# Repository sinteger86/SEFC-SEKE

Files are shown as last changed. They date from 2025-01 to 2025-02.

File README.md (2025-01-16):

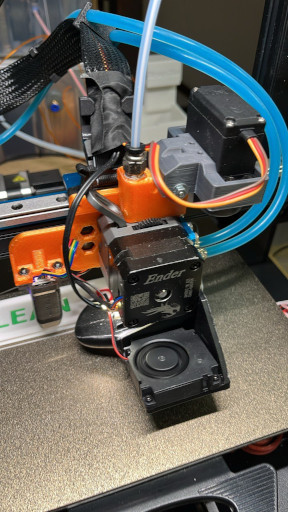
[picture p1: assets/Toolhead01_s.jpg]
Toolhead with SEFC

# SEFC
Sprite Extruder Filament Cutter

After building the ERCF, v1.1 in my case, I went through the battle of calibrate it.
Everything went fine, after I found the right top hats. But, the tip forming calibration
time arrived! And I didnt, and still dont, use a Voron-style toolhead, so there is no 
filament sensors. I spent many hours, asked in the forums and channels, but I wasnt able
to have it in a reliable way. It worked but not always :(

So I decided to look for a filament cutter. I bought a EREC kit from AliExpress and I was
thinking to upgrade my ERCF from version 1.1 to version 2.0. But I started to pay attencion
in the tip that I was getting from the tip forming process. It was not regular when it didnt
work, sometimes a very long string sometimes a short one, and I thought how will EREC deal with
these situations?

Then I decide to look for a toolhead filament cutter, but most of the projects were for a Voron-like
toolhead, until I found the "Sprite Extruder Filament Cutter (SEFC)" from DrawModelPrint, 
https://www.thingiverse.com/thing:6629071.

I built it but didn't work for me as the stepmotor couldnt press the arm strong enough to cut 
the filament.

I decided to look for a filament cutter servo-driven, but I couldnt find any project for the
sprite extruder. At some point I came across with the "Filament-Cutter for Bondtech LGX-Lite Extruder"
from technik.gegg, https://thangs.com/designer/technik.gegg/3d-model/Filament-Cutter%20for%20Bondtech%20LGX-Lite%20Extruder-69552.

I tought then, how about I merge these two projects With that, SEFC was born.

Today I am using it and it has been working fine so far. It is not perfect but it does the job. 

As the printer is using the original board, there is no available pin to connect the servo control,
to overcome it, I bought a RP2040 Zero from AliExpress and connect it to the PAD7 (or SonicPad) and 
add the configuration and macros. 

If you build it, let me know how it works for you. 

## Material

1x Compression Spring 15mm 0.4mm OD (0.4x5x15mm) 
    https://amzn.eu/d/ak1jHkr
1x Blade #4 (need to cut it so the body is 10mm outside the block) 
    https://www.amazon.nl/dp/B08J6G87PL
    I bought this kit as I was trying different blade models
1x Servo MG996R from the EREC kit from Seleadlab (AliExpress)
    https://a.aliexpress.com/_EIvgRve
    I only used the servo
1x Straight Pneumatic Push fittings
    https://www.amazon.nl/dp/B0D87GVJ92

and the parts to print in the STL folder

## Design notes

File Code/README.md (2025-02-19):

# Configuration Section
The configuration is based on adding 2 files (in my case, as I used a RP2040Zero to drive the servo):

## Servo Board (RP2040Zero)
Filename: rp2040.cfg
Include position at printer.cfg: Any place.
Description: This file create the servo and led pins that are used by the macros

## Cutter macro
Filename: tip-cutter.cfg
Include position at printer.cfg: Before the mmu configuration
Description: This file contains the macros that will perform the filament purge and cut. 

## Example:
[include tip-cutter.cfg]
[include mmu/base/*.cfg]
[include mmu/optional/client_macros.cfg]
[include rp2040.cfg]
[include mainsail.cfg]

# Happy-Hare configuration:
on "mmu_macro_vars.cfg":
    variable_user_post_load_extension     : 'MCPURGE'	; Executed after default logic but before restoring toolhead position

on "mmu_parameters.cfg":
    post_form_tip_macro: MCCUTTIP			# Called immediately after tip forming

"Fake" tip forming:
variable_cooling_tube_position  : 30		; Start of cooling tube. DragonST:35, DragonHF:30, Mosquito:30, Revo:35, RapidoHF:27
variable_cooling_tube_length    : 1		; Movement length. DragonST:15, DragonHF:10, Mosquito:20, Revo:10, RapidoHF:10
variable_initial_cooling_speed  : 2.2		; Inital slow movement (mm/s) to solidify tip and cool string if formed
variable_final_cooling_speed    : 30		; Fast movement (mm/s) Too fast: tip deformation on eject, Too Slow: long string/no seperation
variable_cooling_moves          : 1		; Number of back and forth cooling moves to make (2-4 is a good start)

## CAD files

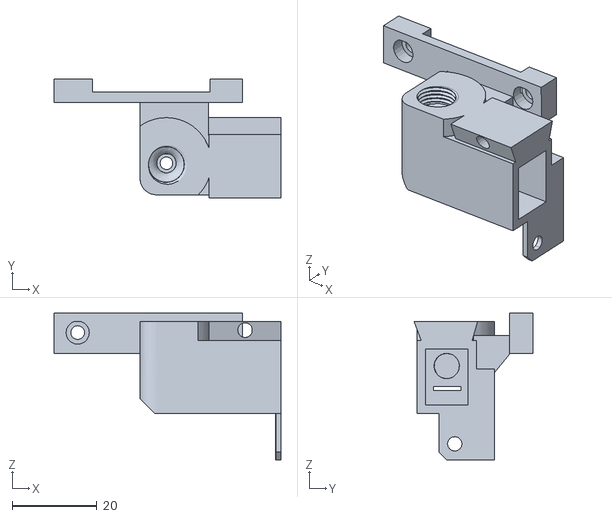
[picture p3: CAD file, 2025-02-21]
STL/SEFC-SEKE v0.91.stl
53.7 x 28.1 x 34.7

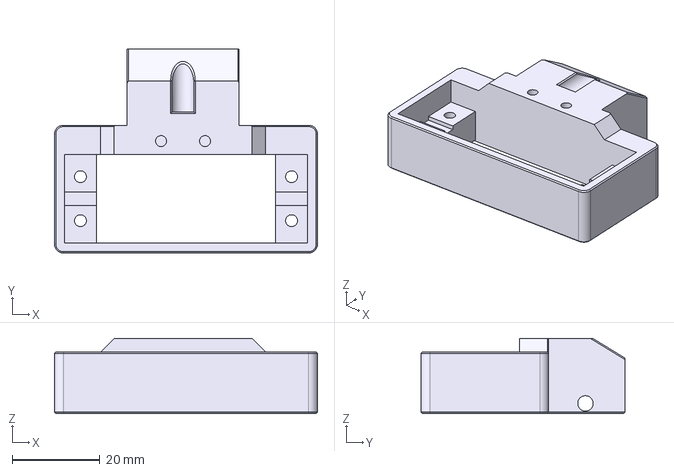
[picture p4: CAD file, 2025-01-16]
STL/SpriteFilamentCutter-BodyServoBase.step
59.8 x 46.4 x 17.1 mm

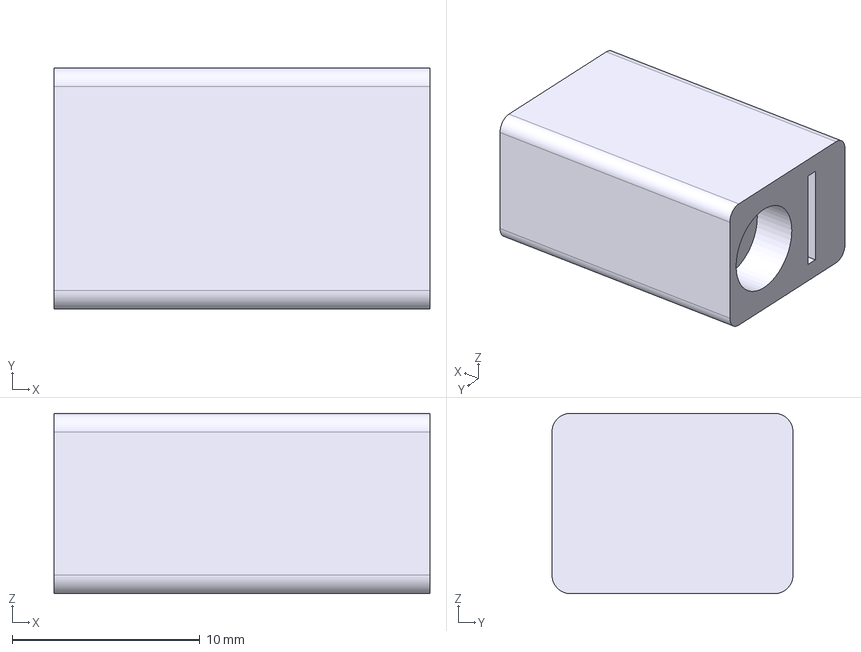
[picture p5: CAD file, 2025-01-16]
STL/MC3D_SpríteExtruder_FilamentCutter_block_v2.3-Body.step
20.0 x 12.8 x 9.60 mm

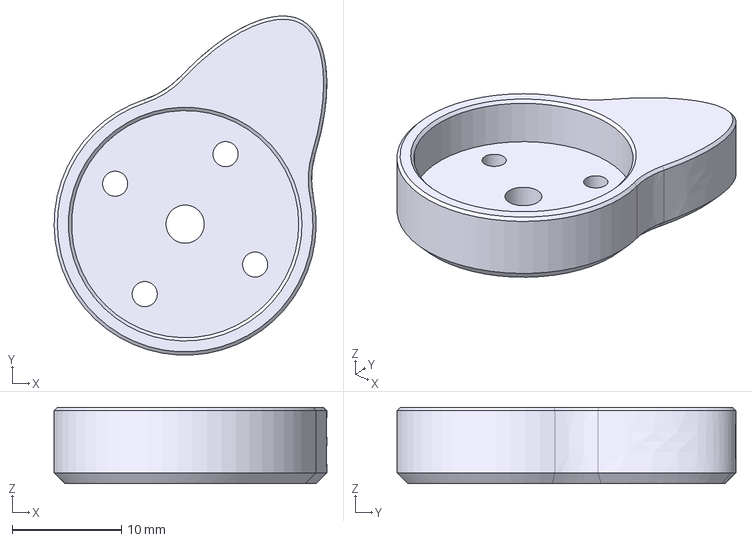
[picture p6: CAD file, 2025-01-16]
STL/SpriteFilamentCutter-BodyServoGear.step
25.0 x 31.0 x 7.00 mm

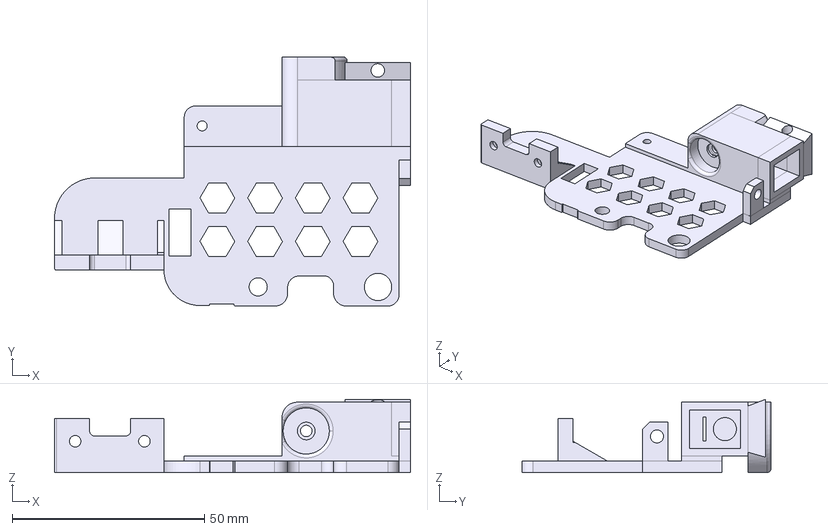
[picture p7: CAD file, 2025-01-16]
STL/MC3D_SpríteExtruder_FilamentCutter_v2.3-Body.step
92.5 x 64.7 x 19.0 mm

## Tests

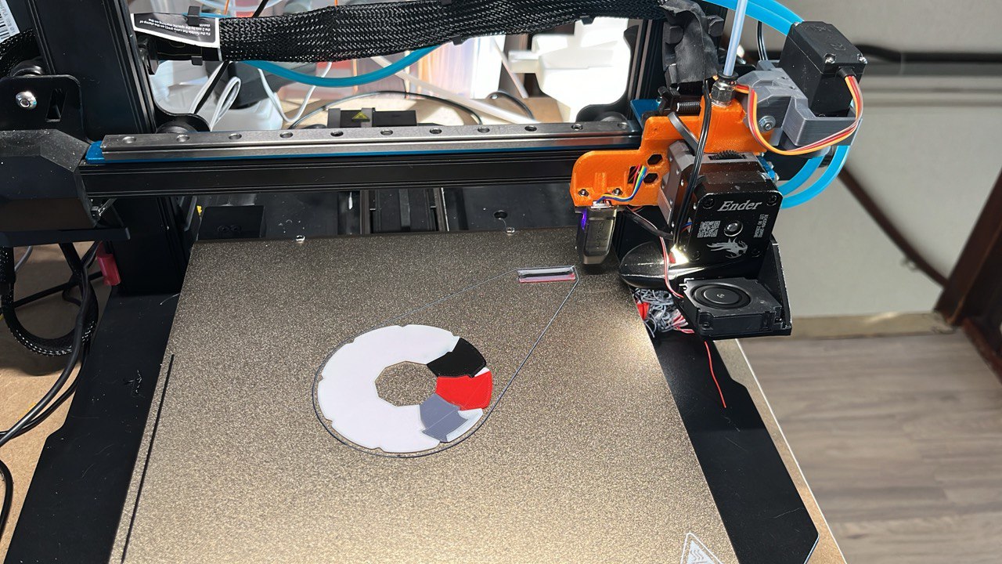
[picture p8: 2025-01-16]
assets/Test01.jpg

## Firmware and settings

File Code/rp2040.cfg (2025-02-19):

[mcu rp2040]
# find with: ls -alh /dev/serial/by-id/usb-Klipper_rp2040*
#serial: /dev/serial/by-id/usb-Klipper_rp2040_5044506118C9541C-if00
serial: /dev/serial/by-id/usb-Klipper_rp2040_5044506120A9A51C-if00

[temperature_sensor rp2040_temp]
sensor_type: temperature_mcu
sensor_mcu: rp2040

[neopixel rp2040_rgb]
pin: rp2040:gpio16
#color_order: GRB
initial_GREEN: 0.2

[servo headcutter]
pin: rp2040:gpio29
initial_angle: 90
maximum_servo_angle = 90
minimum_pulse_width = 0.001
maximum_pulse_width = 0.002

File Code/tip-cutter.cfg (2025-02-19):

[gcode_macro MCPURGE]
description: Purge filament after load
gcode:
    # Save state
    SAVE_GCODE_STATE NAME=MC_PURGE_state

    # Purge
    MMU_SYNC_GEAR_MOTOR SYNC=1
    G92
    G1 E110 F350
    G92
    # Retract a little to prevent oozing
    G1 E-5 F500
    G92
    MMU_SYNC_GEAR_MOTOR SYNC=1

    # Restore state
    RESTORE_GCODE_STATE NAME=MC_PURGE_state

[gcode_macro MCCUTTIP]
description: Cut filament using the SEFC toolhead with servo
gcode:
    {% set final_eject = params.FINAL_EJECT|default(0)|int %}
    {% set vars = printer['gcode_macro _MMU_FORM_TIP_VARS'] %}
    {% set park_vars = printer['gcode_macro _MMU_PARK'] %}
    {% set unloading_speed_start = vars['unloading_speed_start']|int %}
    {% set unloading_speed = vars['unloading_speed']|int %}
    {% set ramming_volume = vars['ramming_volume']|float %}
    {% set ramming_volume_standalone = vars['ramming_volume_standalone']|float %}
    {% set cooling_tube_length = vars['cooling_tube_length']|float %}
    {% set cooling_tube_position = vars['cooling_tube_position']|float %}
    {% set initial_cooling_speed = vars['initial_cooling_speed']|int %}
    {% set final_cooling_speed = vars['final_cooling_speed']|int %}
    {% set cooling_moves = vars['cooling_moves']|int %}
    {% set toolchange_temp = vars['toolchange_temp']|default(0)|int %}
    {% set use_skinnydip = vars['use_skinnydip']|default(false)|lower == 'true' %}
    {% set use_fast_skinnydip = vars['use_fast_skinnydip']|default(false)|lower == 'true' %}
    {% set skinnydip_distance = vars['skinnydip_distance']|float %}
    {% set dip_insertion_speed = vars['dip_insertion_speed']|int %}
    {% set dip_extraction_speed = vars['dip_extraction_speed']|int %}
    {% set melt_zone_pause = vars['melt_zone_pause']|default(0)|int %}
    {% set cooling_zone_pause = vars['cooling_zone_pause']|default(0)|int %}
    {% set extruder_eject_speed = vars['extruder_eject_speed']|int %}
    {% set parking_distance = vars['parking_distance']|default(0)|float %}
    {% set orig_temp = printer.extruder.target %}
    {% set next_temp = params.NEXT_TEMP|default(orig_temp)|int %}

    # Useful state for customizing operations depending on mode
    {% set runout = printer.mmu.runout %}
    {% set printing = printer.mmu.print_state == 'printing' %}

    SAVE_GCODE_STATE NAME=MC_CUT_TIP_state

    # Execute the cut
    SET_LED LED=rp2040_rgb RED=0 GREEN=0 BLUE=0.2
    SET_SERVO SERVO=headcutter ANGLE=28
    G4 P900
    SET_SERVO SERVO=headcutter ANGLE=90
    G4 P900
    SET_SERVO SERVO=headcutter ANGLE=28
    G4 P900
    SET_SERVO SERVO=headcutter ANGLE=90
    G4 P900
    SET_LED LED=rp2040_rgb RED=0 GREEN=0.2 BLUE=0

    # Restore state
    RESTORE_GCODE_STATE NAME=MC_CUT_TIP_state

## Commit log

2025-01-16 First project commit
    [MC3D_SpríteExtruder_FilamentCutter_block_v2.3-Body.step, MC3D_SpríteExtruder_FilamentCutter_v2.3-Body.step, SpriteFilamentCutter-BodyServoBase.step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]
2025-02-19 Add reference configuration code
    [rp2040.cfg, tip-cutter.cfg]
2025-02-21 Add files via upload
    Model of the main body designed to work with the Ender 3 V3 SE & KE versions of the Sprite extruder. Note: requires a non-stock fan shroud, the factory one gets all in the way of everything.
    [SEFC-SEKE v0.91.stl]
